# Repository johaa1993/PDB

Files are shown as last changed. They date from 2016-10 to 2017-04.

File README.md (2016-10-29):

# PDB

# Kill switch
The goal is to switch high power with low power (TTL logic level).
If somethings goes wrong then the user might want to kill the system until further damages happens.

Mechanical relay or MOSFET can be used for such application.

## MOSFET driver
The MOSFET can be damaged if driven incorectly.

### Drain-source resistance `R_ds`
Applying gate-source voltage will decrease drain-source resistance over time. If the drain-source resistance decreases too slow while drain-source current is conducted then the MOSFET will heat up and possably get damaged. The time it takes to reach fully turned on MOSFET depends on gate capacitance, gate resistance and the MOSFET gate driver ability to deliver current.

### Gate-source voltage `V_GS`
Applying too high gate-source voltage will damage the MOSFET.

### Parasitic oscillation
The MOSFET internal capacitance and the wires inductance combined will inevitably create a RLC curcuit.
A step response on the `V_GS` will have a oscilation. Higher gate resistance => higher damping, higher switch time. Lower gate resistance => lower damping, lower switch time.
It's up to the user to find a fine balance between the switch time and parasitic oscillation.

### [LM5050](http://www.ti.com/lit/ds/symlink/lm5050-1-q1.pdf)
MOSFET gate driver. 

http://toshiba.semicon-storage.com/us/design-support/document/application-note.html
Application Precautions: Power MOSFET Application Notes

### More
Taking all these into consideration when designing a MOSFET driver is a hard task.

# Current sensor
The goal is to measure the both high current, low current.

# Fuse
The goal is too protect from short curcuit.

# Power status
The goal is to check if there power on the line.

# Battery cell monitor
The goal is to check if the battery cell is to low.

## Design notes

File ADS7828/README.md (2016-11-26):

# ADC to I2C test circuit for PDB

This circuit is to test the [ADS7828](http://www.ti.com/lit/ds/symlink/ads7828.pdf)

## ADS7828

>The [ADS7828](http://www.ti.com/lit/ds/symlink/ads7828.pdf) is a single-supply, low-power, 12-bit data
>acquisition device that features a serial I2C interface and an
>8-channel multiplexer. The Analog-to-Digital (A/D) converter
>features a sample-and-hold amplifier and internal,
>asynchronous clock. The combination of an I2C serial,
>2-wire interface and micropower consumption makes the
>ADS7828 ideal for applications requiring the A/D converter to
>be close to the input source in remote locations and for
>applications requiring isolation. The ADS7828 is available in
>a TSSOP-16 package.

## Test circuit

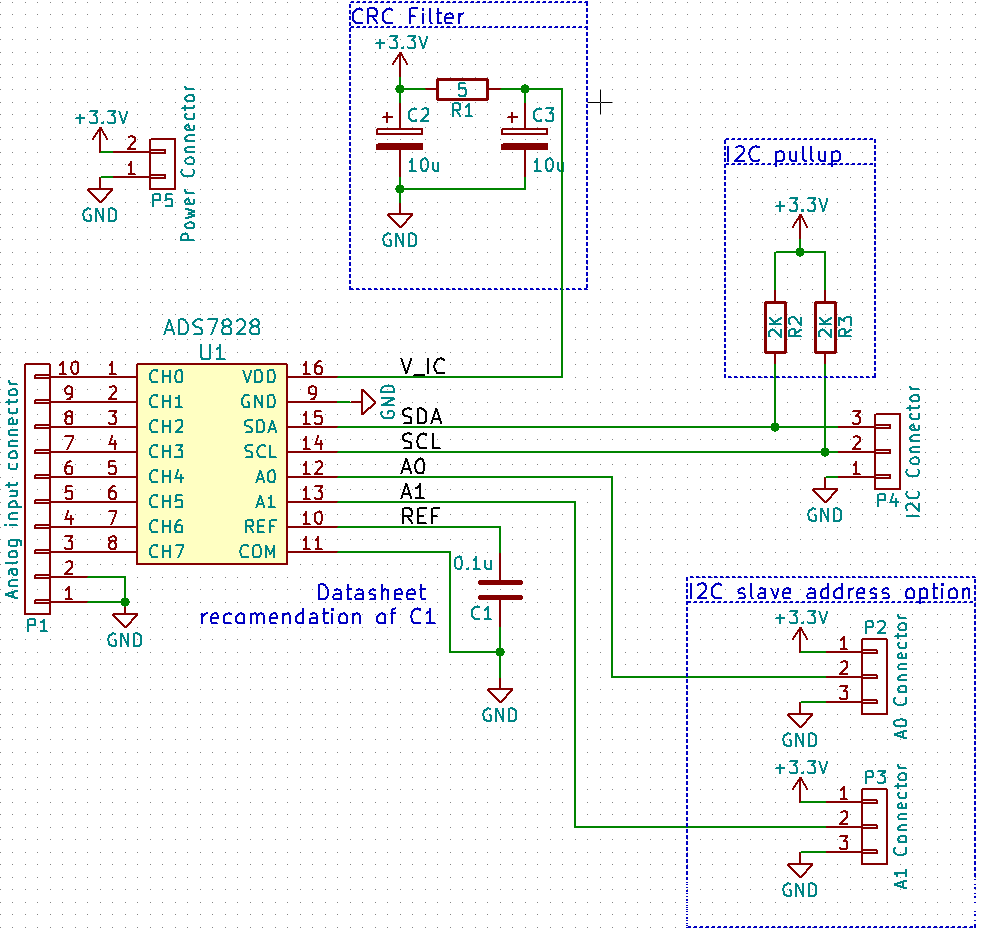
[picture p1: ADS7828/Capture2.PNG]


### CRC Filter
The CRC filter reduces noise for the `V_IC`.

### I2C pull-up
> I2C are open drain, which means that they can pull a signal line low, but they are unable to drive it high.

The I2C pull-up is there in case of microcontroller is not having a internal pull-up.

### I2C slave address option
`3.3V` or `GND` connected to `A0` and `A1` is required in order to provide a slave address. The 7 bit slave address is `(1, 0, 0, 1, 0, A1, A0)` where `GND` is logic a `0` and `3.3V` is a logic `1`.

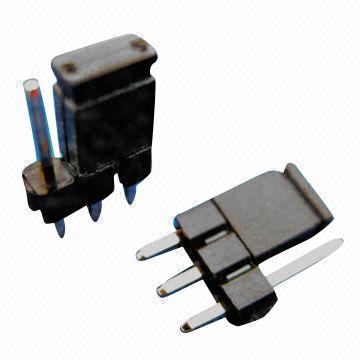
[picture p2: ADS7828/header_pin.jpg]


If header pin for `P2` and `P3` is used, an header pin jumper can be used to select slave address.

### Internal reference voltage
If 3.3V is used then `REF` does not need external voltage.

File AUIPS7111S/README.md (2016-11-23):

# AUIPS7111S

> The [AUIPS7111S](http://www.farnell.com/datasheets/1441780.pdf) is a fully protected four terminal high
> side switch. It features current sensing, over-current, over-
> temperature, ESD protection and drain to source active
> clamp. When the input voltage Vcc - Vin is higher than the
> specified threshold, the output power Mosfet is turned on.
> When the Vcc - Vin is lower than the specified Vil
> threshold, the output Mosfet
> is turned off. The Ifb pin is
> used for current sensing.

## AUIPS7111S Test curcuit

This is a prototype sub part of PDB.

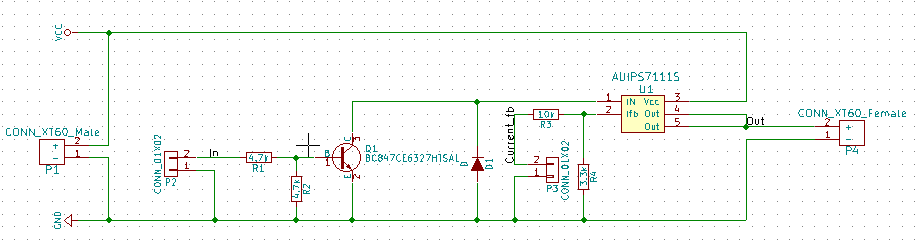
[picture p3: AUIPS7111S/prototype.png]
Image of prototype


The voltage across R4 is `V_R4 = R_4 * I_fb`. So we can configurate the R4 to set the current sense voltage propotional constant to current draw.

`V_R4 = R_4 * I_VCC_Out / Ratio`

### Parts

| Part  | Function  |
|-----|---|
| P1  | Power input |
| P4  | Power output  |
| R1  | Current limiter for BJT. Prevent destroying the BJT or waste power.  |
| R2  | Passive pull down for BJT. We want to make sure the U1 is passively off in case of signal `In` is high impedance.  |
| D1  | Protection for BJT in case of reverse current.  |
| U1  | Switch, current sensing.  |
| R4  | Voltage gain for current sensing. Resistance from `I_fb` to `GND` is max 1.5k [datasheet](http://www.farnell.com/datasheets/1441780.pdf)  |
| R3  | Protection for U1. Resistance from `I_fb` to `GND` is max 1.5k [datasheet](http://www.farnell.com/datasheets/1441780.pdf)  |
| P2  | Input. Connector to control the U1. |
| P3  | Output. Current feedback. |

### Truth table
| `P2_In`  | `U1`  |
|---|---|
| High | On |
| Low | Off |
| High impedance | Off |

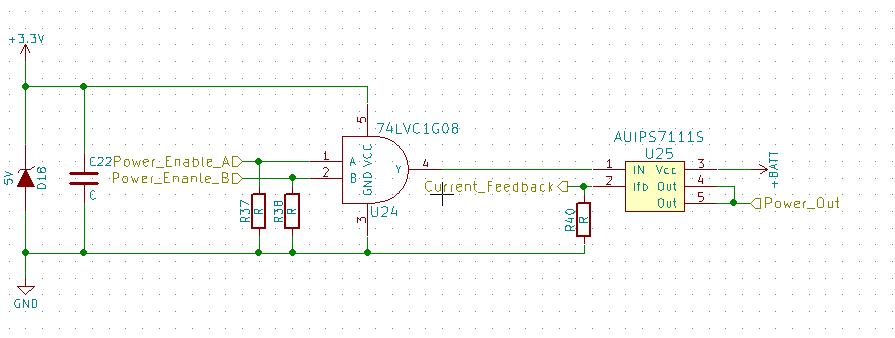
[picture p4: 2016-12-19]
PDB5/concept_pwr_logic.PNG

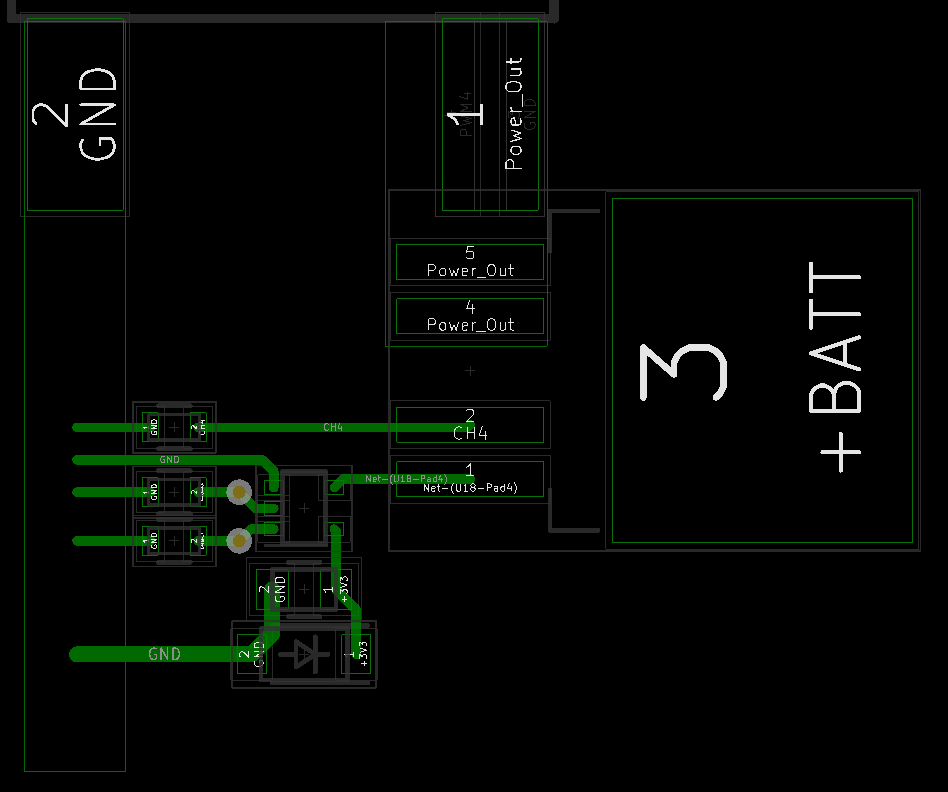
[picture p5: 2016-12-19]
PDB5/concept_pwr_switch_2.PNG

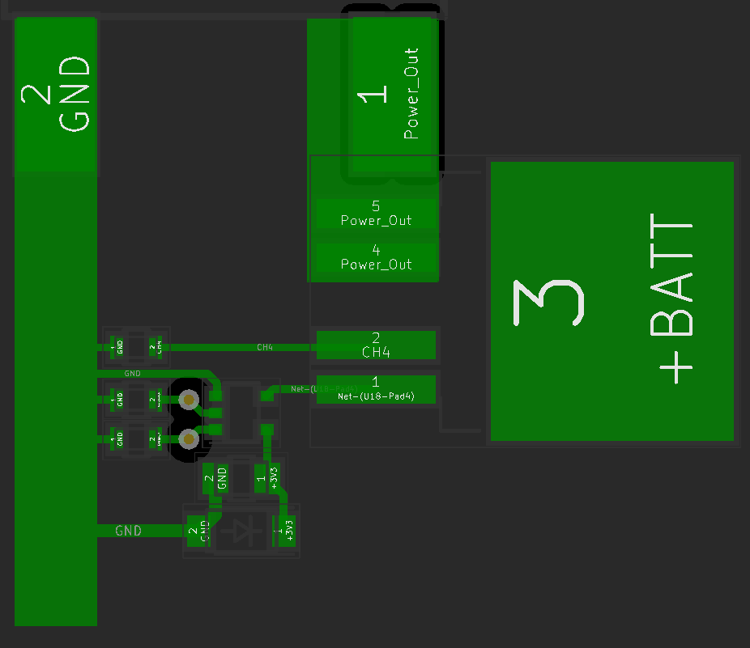
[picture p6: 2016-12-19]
PDB5/concept_pwr_switch.PNG

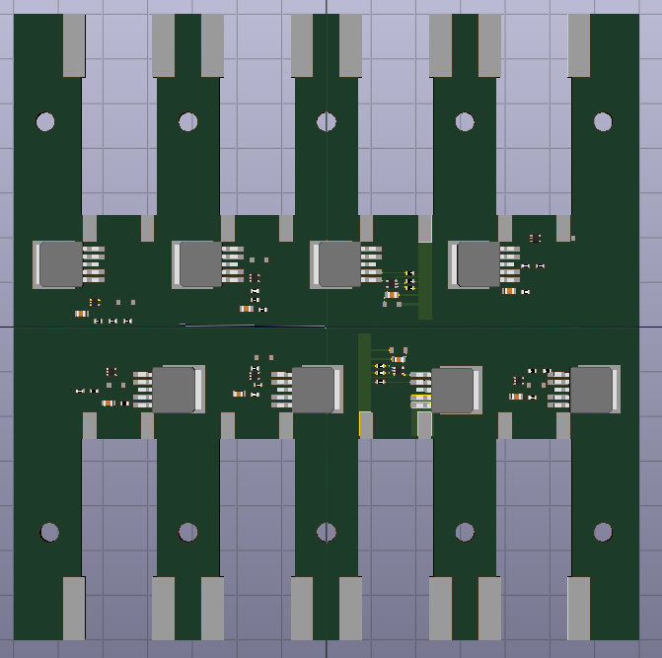
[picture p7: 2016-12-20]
PDB5/concept_1.PNG

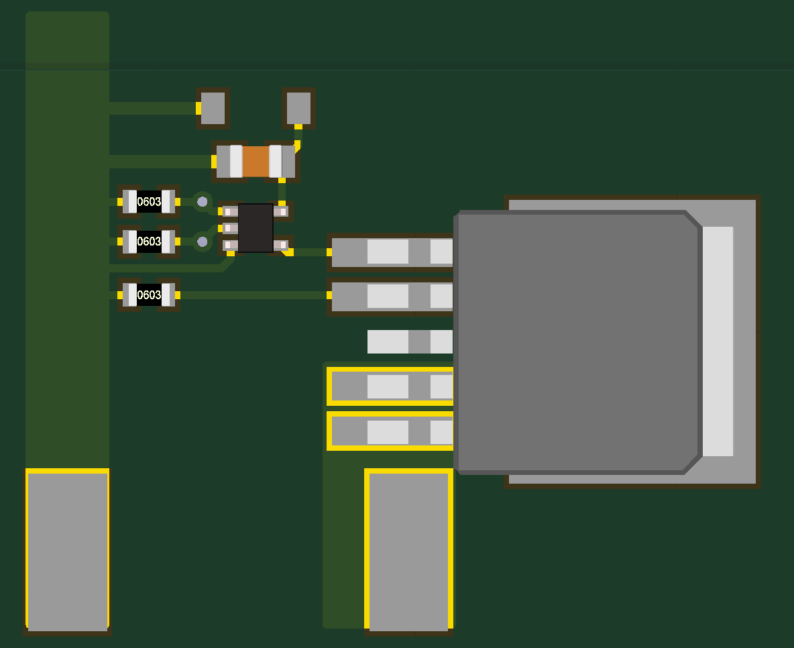
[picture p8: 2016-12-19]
PDB5/concept_pwr_switch_3.PNG

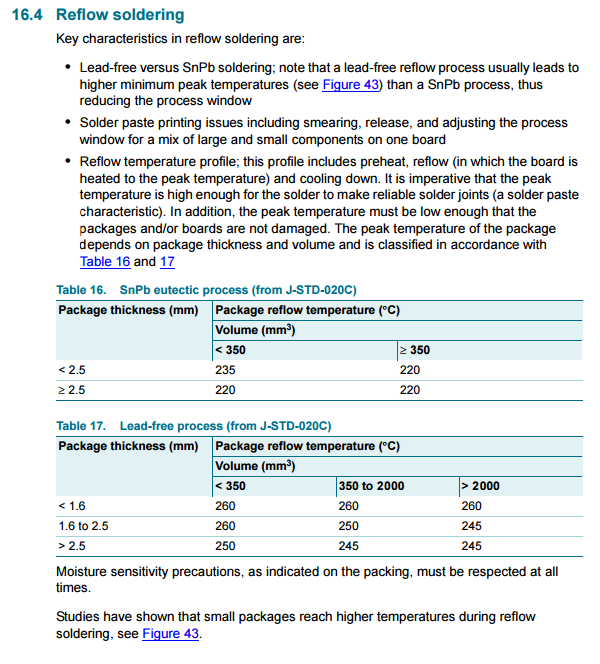
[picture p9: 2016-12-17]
PDB5/Reflow.PNG

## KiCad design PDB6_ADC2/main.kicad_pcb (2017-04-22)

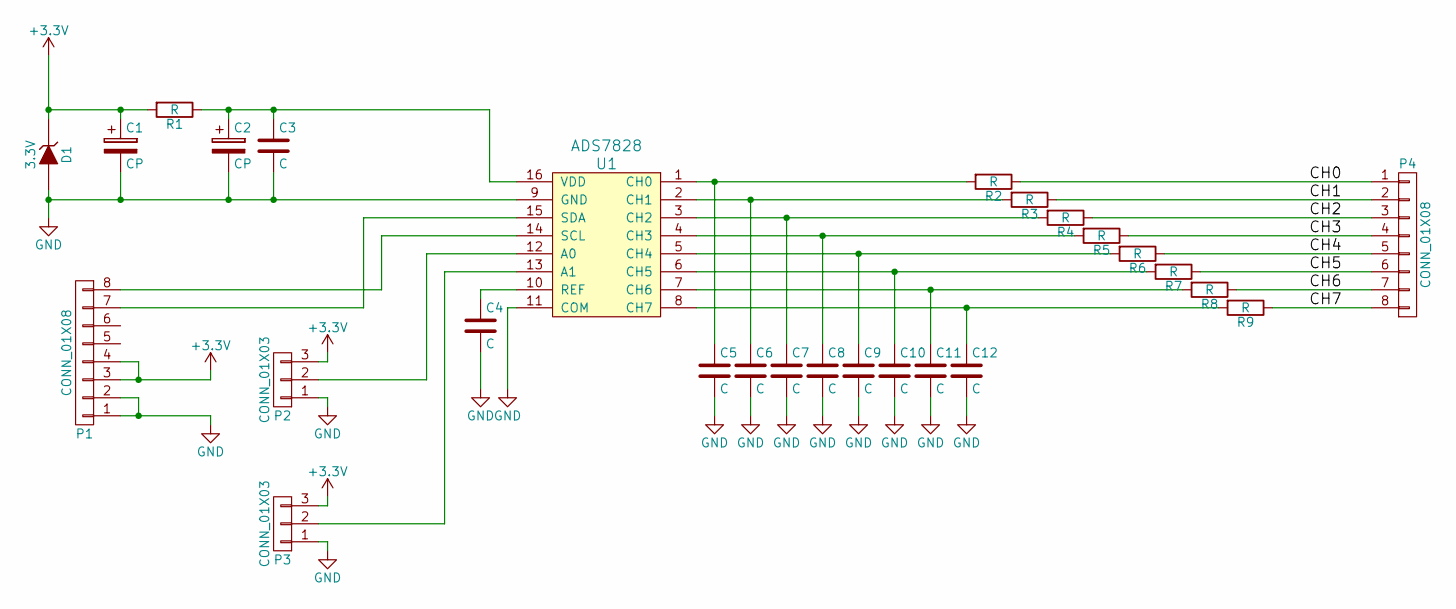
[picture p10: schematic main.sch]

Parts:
C1, C2: CP; SMD-1206_Pol
C3, C4, C5, C6, C7, C8, C9, C10, C11, C12: C; C_0805
D1: 3.3V; SOD-123
P1, P4: CONN_01X08; Pin_Header_Straight_1x08_Pitch2.00mm
P2, P3: CONN_01X03; Pad_3
R1, R2, R3, R4, R5, R6, R7, R8, R9: R; R_0805
U1: ADS7828; TSSOP-16_4.4x5mm_Pitch0.65mm

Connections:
+3V3: C1.1, D1.1 (K), P1.3, P1.4, P2.3, P3.3, R1.2
/CH0: P4.1, R2.1
/CH1: P4.2, R3.1
/CH2: P4.3, R4.1
/CH3: P4.4, R5.1
/CH4: P4.5, R6.1
/CH5: P4.6, R7.1
/CH6: P4.7, R8.1
/CH7: P4.8, R9.1
GND: C1.2, C2.2, C3.2, C4.2, C5.2, C6.2, C7.2, C8.2, C9.2, C10.2, C11.2, C12.2, D1.2 (A), P1.1, P1.2, P2.1, P3.1, U1.9 (GND), U1.11 (COM)
unnamed: C2.1, C3.1, R1.1, U1.16 (VDD)
unnamed: C4.1, U1.10 (REF)
unnamed: C5.1, R2.2, U1.1 (CH0)
unnamed: C6.1, R3.2, U1.2 (CH1)
unnamed: C7.1, R4.2, U1.3 (CH2)
unnamed: C8.1, R5.2, U1.4 (CH3)
unnamed: C9.1, R6.2, U1.5 (CH4)
unnamed: C10.1, R7.2, U1.6 (CH5)
unnamed: C11.1, R8.2, U1.7 (CH6)
unnamed: C12.1, R9.2, U1.8 (CH7)
unnamed: P1.7, U1.15 (SDA)
unnamed: P1.8, U1.14 (SCL)
unnamed: P2.2, U1.12 (A0)
unnamed: P3.2, U1.13 (A1)

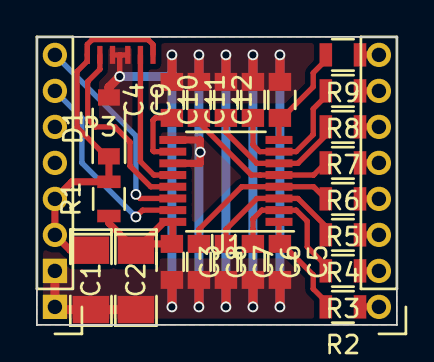
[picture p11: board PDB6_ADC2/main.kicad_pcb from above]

Board: 2 copper layers, 20.0 x 16.0 mm, 27 parts (0 on the bottom side), 24 nets.

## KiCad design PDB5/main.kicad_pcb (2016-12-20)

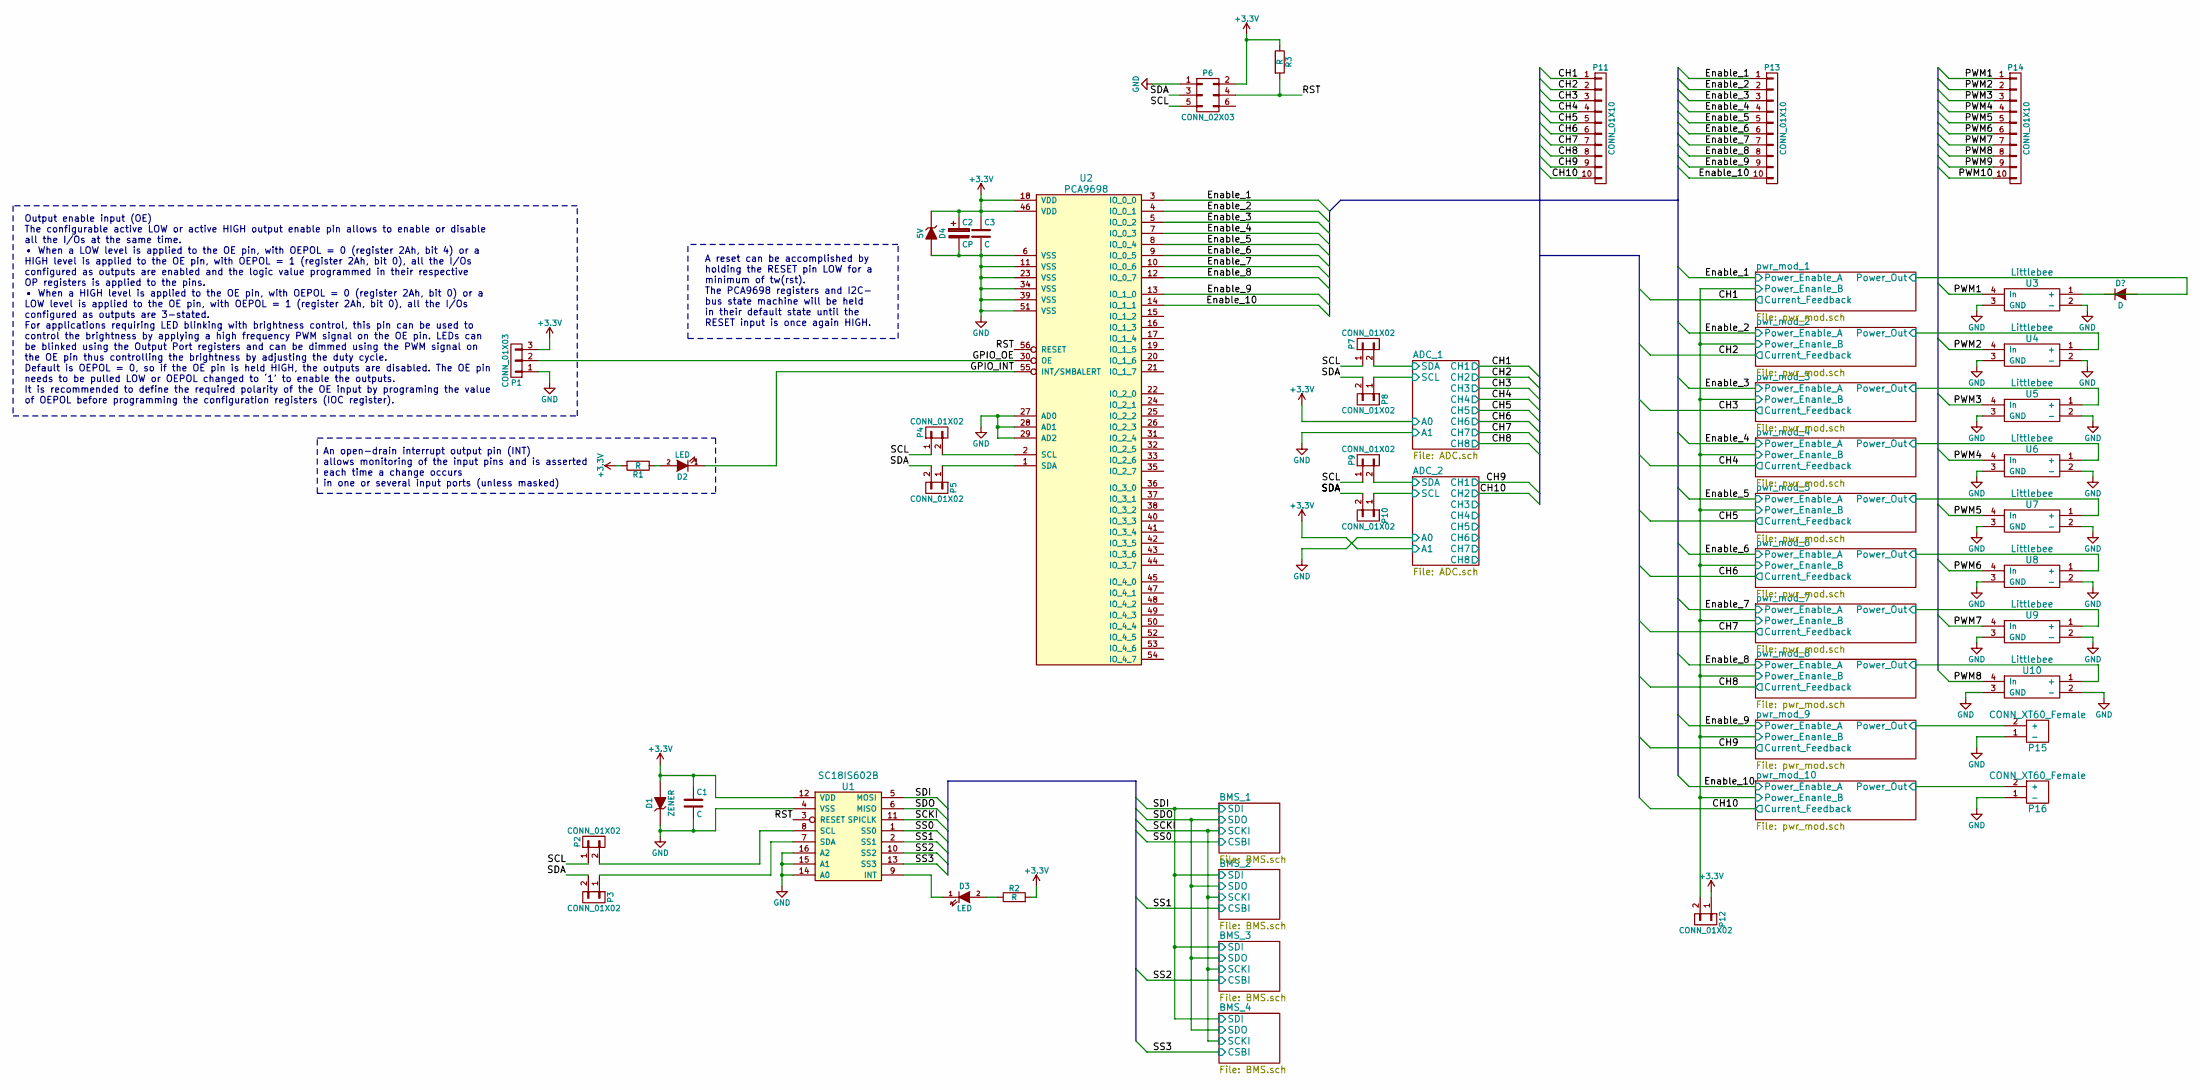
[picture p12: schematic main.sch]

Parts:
C1, C3: C; C_0805
C2: CP; SMD-2010_Pol
D1: ZENER; SOD-123
D2, D3: LED; LED_0603
D4: 5V; SOD-123
P1: CONN_01X03; Pin_Header_Straight_1x03
P2, P3, P4, P5, P7, P8, P9, P10, P12: CONN_01X02; Pin_Header_Straight_1x02
P6: CONN_02X03; Pin_Header_Straight_2x03
P11, P13, P14: CONN_01X10; Pin_Header_Straight_1x10
P15, P16: CONN_XT60_Female; XT60
R1, R2: R; R_0603
R3: R
U1: SC18IS602B; TSSOP-16_4.4x5mm_Pitch0.65mm
U2: PCA9698; TSSOP-56_6.1x14mm_Pitch0.5mm
U3, U4, U5, U6, U7, U8, U9, U10: Littlebee

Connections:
+3V3: C1.1, C2.1, C3.1, D1.2 (A), D4.1 (K), P1.3, P6.2, P12.1, R1.2, R2.2, R3.1, U1.12 (VDD), U2.18 (VDD), U2.46 (VDD); also elsewhere on the board
/ADC_1/SCL: P8.1; also elsewhere on the board
/ADC_1/SDA: P7.2; also elsewhere on the board
/ADC_2/SCL: P10.1; also elsewhere on the board
/ADC_2/SDA: P9.2; also elsewhere on the board
/CH1: P11.1; also elsewhere on the board
/CH2: P11.2; also elsewhere on the board
/CH3: P11.3; also elsewhere on the board
/CH4: P11.4; also elsewhere on the board
/CH5: P11.5; also elsewhere on the board
/CH6: P11.6; also elsewhere on the board
/CH7: P11.7; also elsewhere on the board
/CH8: P11.8; also elsewhere on the board
/CH9: P11.9; also elsewhere on the board
/CH10: P11.10; also elsewhere on the board
/Enable_1: P13.1, U2.3 (IO_0_0); also elsewhere on the board
/Enable_2: P13.2, U2.4 (IO_0_1); also elsewhere on the board
/Enable_3: P13.3, U2.5 (IO_0_2); also elsewhere on the board
/Enable_4: P13.4, U2.7 (IO_0_3); also elsewhere on the board
/Enable_5: P13.5, U2.8 (IO_0_4); also elsewhere on the board
/Enable_6: P13.6, U2.9 (IO_0_5); also elsewhere on the board
/Enable_7: P13.7, U2.10 (IO_0_6); also elsewhere on the board
/Enable_8: P13.8, U2.12 (IO_0_7); also elsewhere on the board
/Enable_9: P13.9, U2.13 (IO_1_0); also elsewhere on the board
/Enable_10: P13.10, U2.14 (IO_1_1); also elsewhere on the board
/GPIO_INT: D2.1 (K), U2.55 (INT/SMBALERT)
/GPIO_OE: P1.2, U2.30 (OE)
/PWM1: P14.1, U3.4 (In)
/PWM2: P14.2, U4.4 (In)
/PWM3: P14.3, U5.4 (In)
/PWM4: P14.4, U6.4 (In)
/PWM5: P14.5, U7.4 (In)
/PWM6: P14.6, U8.4 (In)
/PWM7: P14.7, U9.4 (In)
/PWM8: P14.8, U10.4 (In)
/RST: P6.4, R3.2, U1.3 (RESET), U2.56 (RESET)
/SCKI: U1.11 (SPICLK); also elsewhere on the board
/SCL: P2.1, P4.1, P6.5, P7.1, P9.1
/SDA: P3.2, P5.2, P6.3, P8.2, P10.2
/SDI: U1.5 (MOSI); also elsewhere on the board
/SDO: U1.6 (MISO); also elsewhere on the board
/SS0: U1.1 (SS0); also elsewhere on the board
/SS1: U1.2 (SS1); also elsewhere on the board
/SS2: U1.10 (SS2); also elsewhere on the board
/SS3: U1.13 (SS3); also elsewhere on the board
/pwr_mod_1/Power_Enanle_B: P12.2; also elsewhere on the board
/pwr_mod_1/Power_Out: U3.1 (+); also elsewhere on the board
/pwr_mod_2/Power_Out: U4.1 (+); also elsewhere on the board
/pwr_mod_3/Power_Out: U5.1 (+); also elsewhere on the board
/pwr_mod_4/Power_Out: U6.1 (+); also elsewhere on the board
/pwr_mod_5/Power_Out: U7.1 (+); also elsewhere on the board
/pwr_mod_6/Power_Out: U8.1 (+); also elsewhere on the board
/pwr_mod_7/Power_Out: U9.1 (+); also elsewhere on the board
/pwr_mod_8/Power_Out: U10.1 (+); also elsewhere on the board
/pwr_mod_9/Power_Out: P15.2 (+); also elsewhere on the board
/pwr_mod_10/Power_Out: P16.2 (+); also elsewhere on the board
GND: C1.2, C2.2, C3.2, D1.1 (K), D4.2 (A), P1.1, P6.1, P15.1 (-), P16.1 (-), U1.4 (VSS), U1.14 (A0), U1.15 (A1), U1.16 (A2), U2.6 (VSS), U2.11 (VSS), U2.23 (VSS), U2.27 (AD0), U2.28 (AD1), U2.29 (AD2), U2.34 (VSS), U2.39 (VSS), U2.51 (VSS), U3.2 (-), U3.3 (GND), U4.2 (-), U4.3 (GND), U5.2 (-), U5.3 (GND), U6.2 (-), U6.3 (GND), U7.2 (-), U7.3 (GND), U8.2 (-), U8.3 (GND), U9.2 (-), U9.3 (GND), U10.2 (-), U10.3 (GND); also elsewhere on the board
unnamed: D2.2 (A), R1.1
unnamed: D3.1 (K), U1.9 (INT)
unnamed: D3.2 (A), R2.1
unnamed: P2.2, U1.8 (SCL)
unnamed: P3.1, U1.7 (SDA)
unnamed: P4.2, U2.2 (SCL)
unnamed: P5.1, U2.1 (SDA)

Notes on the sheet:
An open-drain interrupt output pin (INT) allows monitoring of the input pins and is asserted each time a change occurs in one or several input ports (unless masked)
Output enable input (OE) The configurable active LOW or active HIGH output enable pin allows to enable or disable all the I/Os at the same time. • When a LOW level is applied to the OE pin, with OEPOL = 0 (register 2Ah, bit 4) or a HIGH level is applied to the OE pin, with OEPOL = 1 (register 2Ah, 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
A reset can be accomplished by holding the RESET pin LOW for a minimum of tw(rst). The PCA9698 registers and I2C- bus state machine will be held in their default state until the RESET input is once again HIGH.

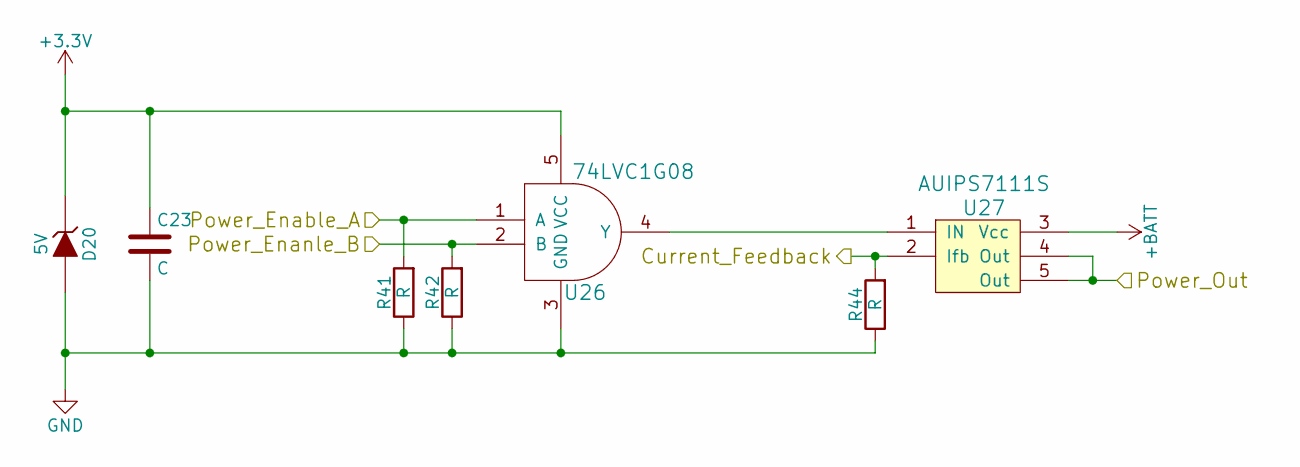
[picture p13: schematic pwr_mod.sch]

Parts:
C4: C; C_0805
D5: 5V; SOD-123
R4, R7, R26: R; R_0603
U11: 74LVC1G08; SOT-353
U12: AUIPS7111S; TO-263-!3

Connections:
+3V3: C4.1, D5.1 (K), U11.5 (VCC); also elsewhere on the board
+BATT: U12.3 (Vcc); also elsewhere on the board
/CH1: R7.2, U12.2 (Ifb); also elsewhere on the board
/Enable_1: R4.2, U11.1 (A); also elsewhere on the board
/pwr_mod_1/Power_Enanle_B: R26.2, U11.2 (B); also elsewhere on the board
/pwr_mod_1/Power_Out: U12.4 (Out), U12.5 (Out); also elsewhere on the board
GND: C4.2, D5.2 (A), R4.1, R7.1, R26.1, U11.3 (GND); also elsewhere on the board
unnamed: U11.4 (Y), U12.1 (IN)

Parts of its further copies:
C5, C18, C19, C20, C21, C22, C23, C24, C25: C; C_0805
D7, D10, D12, D14, D16, D18, D20, D22, D24: 5V; SOD-123
R5, R8, R9, R11, R21, R22, R24, R25, R28, R29, R30, R32, R33, R34, R36, R37, R38, R40, R41, R42, R44, R45, R46, R48, R49, R50, R52: R; R_0603
U13, U16, U18, U20, U22, U24, U26, U28, U30: 74LVC1G08; SOT-353
U14, U17, U19, U21, U23, U25, U27, U29, U31: AUIPS7111S; TO-263-!3

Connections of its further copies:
+3V3: C5.1, C18.1, C19.1, C20.1, C21.1, C22.1, C23.1, C24.1, C25.1, D7.1 (K), D10.1 (K), D12.1 (K), D14.1 (K), D16.1 (K), D18.1 (K), D20.1 (K), D22.1 (K), D24.1 (K), U13.5 (VCC), U16.5 (VCC), U18.5 (VCC), U20.5 (VCC), U22.5 (VCC), U24.5 (VCC), U26.5 (VCC), U28.5 (VCC), U30.5 (VCC); also elsewhere on the board
+BATT: U14.3 (Vcc), U17.3 (Vcc), U19.3 (Vcc), U21.3 (Vcc), U23.3 (Vcc), U25.3 (Vcc), U27.3 (Vcc), U29.3 (Vcc), U31.3 (Vcc); also elsewhere on the board
/CH2: R11.2, U14.2 (Ifb); also elsewhere on the board
/CH3: R24.2, U17.2 (Ifb); also elsewhere on the board
/CH4: R28.2, U19.2 (Ifb); also elsewhere on the board
/CH5: R32.2, U21.2 (Ifb); also elsewhere on the board
/CH6: R36.2, U23.2 (Ifb); also elsewhere on the board
/CH7: R40.2, U25.2 (Ifb); also elsewhere on the board
/CH8: R44.2, U27.2 (Ifb); also elsewhere on the board
/CH9: R48.2, U29.2 (Ifb); also elsewhere on the board
/CH10: R52.2, U31.2 (Ifb); also elsewhere on the board
/Enable_2: R8.2, U13.1 (A); also elsewhere on the board
/Enable_3: R21.2, U16.1 (A); also elsewhere on the board
/Enable_4: R25.2, U18.1 (A); also elsewhere on the board
/Enable_5: R29.2, U20.1 (A); also elsewhere on the board
/Enable_6: R33.2, U22.1 (A); also elsewhere on the board
/Enable_7: R37.2, U24.1 (A); also elsewhere on the board
/Enable_8: R41.2, U26.1 (A); also elsewhere on the board
/Enable_9: R45.2, U28.1 (A); also elsewhere on the board
/Enable_10: R49.2, U30.1 (A); also elsewhere on the board
/pwr_mod_1/Power_Enanle_B: R5.2, R9.2, R22.2, R30.2, R34.2, R38.2, R42.2, R46.2, R50.2, U13.2 (B), U16.2 (B), U18.2 (B), U20.2 (B), U22.2 (B), U24.2 (B), U26.2 (B), U28.2 (B), U30.2 (B); also elsewhere on the board
/pwr_mod_2/Power_Out: U14.4 (Out), U14.5 (Out); also elsewhere on the board
/pwr_mod_3/Power_Out: U17.4 (Out), U17.5 (Out); also elsewhere on the board
/pwr_mod_4/Power_Out: U19.4 (Out), U19.5 (Out); also elsewhere on the board
/pwr_mod_5/Power_Out: U21.4 (Out), U21.5 (Out); also elsewhere on the board
/pwr_mod_6/Power_Out: U23.4 (Out), U23.5 (Out); also elsewhere on the board
/pwr_mod_7/Power_Out: U25.4 (Out), U25.5 (Out); also elsewhere on the board
/pwr_mod_8/Power_Out: U27.4 (Out), U27.5 (Out); also elsewhere on the board
/pwr_mod_9/Power_Out: U29.4 (Out), U29.5 (Out); also elsewhere on the board
/pwr_mod_10/Power_Out: U31.4 (Out), U31.5 (Out); also elsewhere on the board
GND: C5.2, C18.2, C19.2, C20.2, C21.2, C22.2, C23.2, C24.2, C25.2, D7.2 (A), D10.2 (A), D12.2 (A), D14.2 (A), D16.2 (A), D18.2 (A), D20.2 (A), D22.2 (A), D24.2 (A), R5.1, R8.1, R9.1, R11.1, R21.1, R22.1, R24.1, R25.1, R28.1, R29.1, R30.1, R32.1, R33.1, R34.1, R36.1, R37.1, R38.1, R40.1, R41.1, R42.1, R44.1, R45.1, R46.1, R48.1, R49.1, R50.1, R52.1, U13.3 (GND), U16.3 (GND), U18.3 (GND), U20.3 (GND), U22.3 (GND), U24.3 (GND), U26.3 (GND), U28.3 (GND), U30.3 (GND); also elsewhere on the board
unnamed: U13.4 (Y), U14.1 (IN)
unnamed: U16.4 (Y), U17.1 (IN)
unnamed: U18.4 (Y), U19.1 (IN)
unnamed: U20.4 (Y), U21.1 (IN)
unnamed: U22.4 (Y), U23.1 (IN)
unnamed: U24.4 (Y), U25.1 (IN)
unnamed: U26.4 (Y), U27.1 (IN)
unnamed: U28.4 (Y), U29.1 (IN)
unnamed: U30.4 (Y), U31.1 (IN)

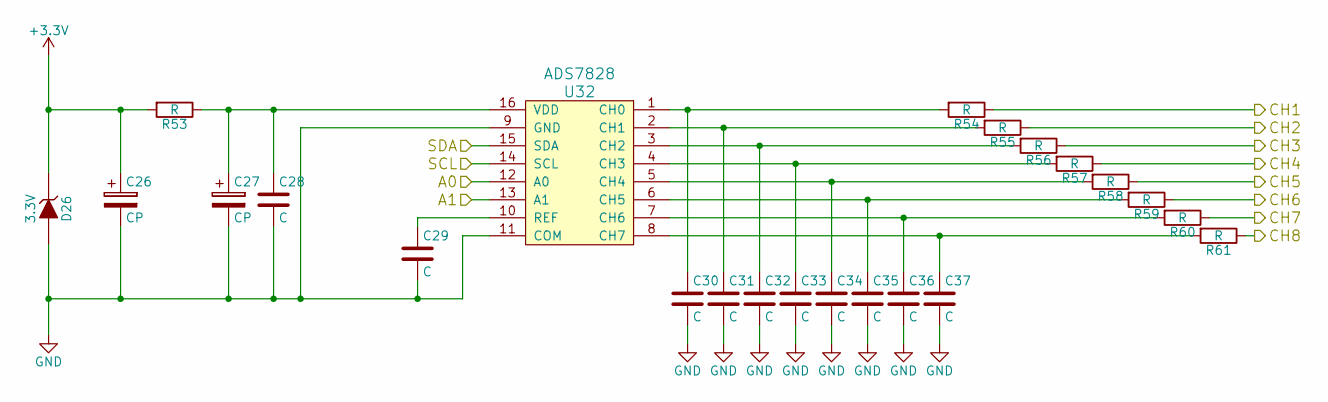
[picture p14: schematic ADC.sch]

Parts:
C6, C7: CP; SMD-2010_Pol
C8, C9, C10, C11, C12, C13, C14, C15, C16, C17: C; C_0805
D9: 3.3V; SOD-123
R12, R13, R14, R15, R16, R17, R18, R19, R20: R; R_0603
U15: ADS7828; TSSOP-16_4.4x5mm_Pitch0.65mm

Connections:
+3V3: C6.1, D9.1 (K), R12.2, U15.12 (A0); also elsewhere on the board
/ADC_1/SCL: U15.14 (SCL); also elsewhere on the board
/ADC_1/SDA: U15.15 (SDA); also elsewhere on the board
/CH1: R13.1; also elsewhere on the board
/CH2: R14.1; also elsewhere on the board
/CH3: R15.1; also elsewhere on the board
/CH4: R16.1; also elsewhere on the board
/CH5: R17.1; also elsewhere on the board
/CH6: R18.1; also elsewhere on the board
/CH7: R19.1; also elsewhere on the board
/CH8: R20.1; also elsewhere on the board
GND: C6.2, C7.2, C8.2, C9.2, C10.2, C11.2, C12.2, C13.2, C14.2, C15.2, C16.2, C17.2, D9.2 (A), U15.9 (GND), U15.11 (COM), U15.13 (A1); also elsewhere on the board
unnamed: C7.1, C8.1, R12.1, U15.16 (VDD)
unnamed: C9.1, U15.10 (REF)
unnamed: C10.1, R13.2, U15.1 (CH0)
unnamed: C11.1, R14.2, U15.2 (CH1)
unnamed: C12.1, R15.2, U15.3 (CH2)
unnamed: C13.1, R16.2, U15.4 (CH3)
unnamed: C14.1, R17.2, U15.5 (CH4)
unnamed: C15.1, R18.2, U15.6 (CH5)
unnamed: C16.1, R19.2, U15.7 (CH6)
unnamed: C17.1, R20.2, U15.8 (CH7)

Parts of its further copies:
C26, C27: CP; SMD-2010_Pol
C28, C29, C30, C31, C32, C33, C34, C35, C36, C37: C; C_0805
D26: 3.3V; SOD-123
R53, R54, R55, R56, R57, R58, R59, R60, R61: R; R_0603
U32: ADS7828; TSSOP-16_4.4x5mm_Pitch0.65mm

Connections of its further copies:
+3V3: C26.1, D26.1 (K), R53.2, U32.13 (A1); also elsewhere on the board
/ADC_2/SCL: U32.14 (SCL); also elsewhere on the board
/ADC_2/SDA: U32.15 (SDA); also elsewhere on the board
/CH9: R54.1; also elsewhere on the board
/CH10: R55.1; also elsewhere on the board
GND: C26.2, C27.2, C28.2, C29.2, C30.2, C31.2, C32.2, C33.2, C34.2, C35.2, C36.2, C37.2, D26.2 (A), U32.9 (GND), U32.11 (COM), U32.12 (A0); also elsewhere on the board
unnamed: C27.1, C28.1, R53.1, U32.16 (VDD)
unnamed: C29.1, U32.10 (REF)
unnamed: C30.1, R54.2, U32.1 (CH0)
unnamed: C31.1, R55.2, U32.2 (CH1)
unnamed: C32.1, R56.2, U32.3 (CH2)
unnamed: C33.1, R57.2, U32.4 (CH3)
unnamed: C34.1, R58.2, U32.5 (CH4)
unnamed: C35.1, R59.2, U32.6 (CH5)
unnamed: C36.1, R60.2, U32.7 (CH6)
unnamed: C37.1, R61.2, U32.8 (CH7)

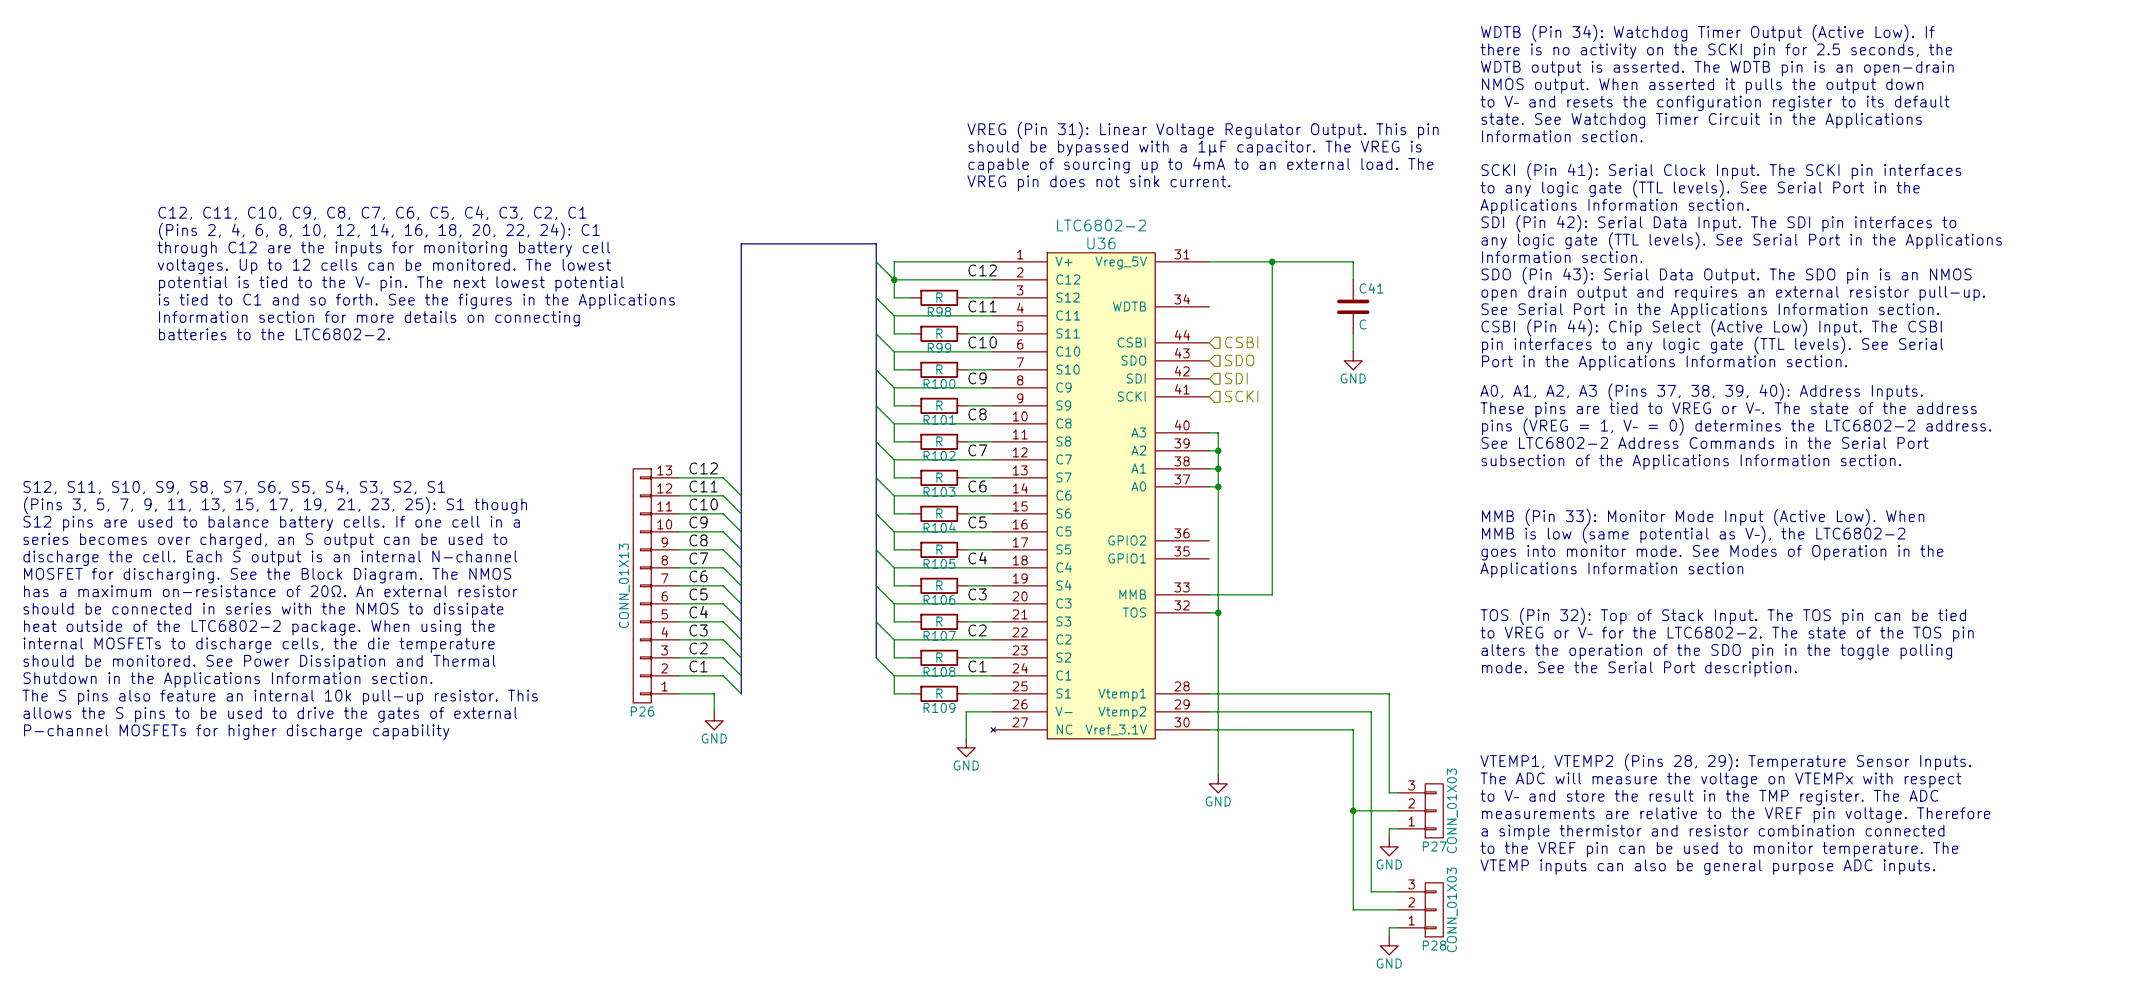
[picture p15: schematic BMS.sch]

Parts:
C38: C; C_0805
P17: CONN_01X13; Pin_Header_Straight_1x13
P18, P19: CONN_01X03; Pin_Header_Straight_1x03
R62, R63, R64, R65, R66, R67, R68, R69, R70, R71, R72, R73: R; R_0805
U33: LTC6802-2; SSOP-44

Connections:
/BMS_1/C1: P17.2, R73.2, U33.24 (C1)
/BMS_1/C2: P17.3, R72.2, U33.22 (C2)
/BMS_1/C3: P17.4, R71.2, U33.20 (C3)
/BMS_1/C4: P17.5, R70.2, U33.18 (C4)
/BMS_1/C5: P17.6, R69.2, U33.16 (C5)
/BMS_1/C6: P17.7, R68.2, U33.14 (C6)
/BMS_1/C7: P17.8, R67.2, U33.12 (C7)
/BMS_1/C8: P17.9, R66.2, U33.10 (C8)
/BMS_1/C9: P17.10, R65.2, U33.8 (C9)
/BMS_1/C10: P17.11, R64.2, U33.6 (C10)
/BMS_1/C11: P17.12, R63.2, U33.4 (C11)
/BMS_1/C12: P17.13, R62.2, U33.1 (V+), U33.2 (C12)
/SCKI: U33.41 (SCKI); also elsewhere on the board
/SDI: U33.42 (SDI); also elsewhere on the board
/SDO: U33.43 (SDO); also elsewhere on the board
/SS0: U33.44 (CSBI); also elsewhere on the board
GND: C38.2, P17.1, P18.1, P19.1, U33.26 (V-), U33.32 (TOS), U33.37 (A0), U33.38 (A1), U33.39 (A2), U33.40 (A3); also elsewhere on the board
unnamed: C38.1, U33.31 (Vreg_5V), U33.33 (MMB)
unnamed: P18.2, P19.2, U33.30 (Vref_3.1V)
unnamed: P18.3, U33.28 (Vtemp1)
unnamed: P19.3, U33.29 (Vtemp2)
unnamed: R62.1, U33.3 (S12)
unnamed: R63.1, U33.5 (S11)
unnamed: R64.1, U33.7 (S10)
unnamed: R65.1, U33.9 (S9)
unnamed: R66.1, U33.11 (S8)
unnamed: R67.1, U33.13 (S7)
unnamed: R68.1, U33.15 (S6)
unnamed: R69.1, U33.17 (S5)
unnamed: R70.1, U33.19 (S4)
unnamed: R71.1, U33.21 (S3)
unnamed: R72.1, U33.23 (S2)
unnamed: R73.1, U33.25 (S1)

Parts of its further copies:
C39, C40, C41: C; C_0805
P20, P23, P26: CONN_01X13; Pin_Header_Straight_1x13
P21, P22, P24, P25, P27, P28: CONN_01X03; Pin_Header_Straight_1x03
R74, R75, R76, R77, R78, R79, R80, R81, R82, R83, R84, R85, R86, R87, R88, R89, R90, R91, R92, R93, R94, R95, R96, R97, R98, R99, R100, R101, R102, R103, R104, R105, R106, R107, R108, R109: R; R_0805
U34, U35, U36: LTC6802-2; SSOP-44

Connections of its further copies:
/BMS_2/C1: P20.2, R85.2, U34.24 (C1)
/BMS_2/C2: P20.3, R84.2, U34.22 (C2)
/BMS_2/C3: P20.4, R83.2, U34.20 (C3)
/BMS_2/C4: P20.5, R82.2, U34.18 (C4)
/BMS_2/C5: P20.6, R81.2, U34.16 (C5)
/BMS_2/C6: P20.7, R80.2, U34.14 (C6)
/BMS_2/C7: P20.8, R79.2, U34.12 (C7)
/BMS_2/C8: P20.9, R78.2, U34.10 (C8)
/BMS_2/C9: P20.10, R77.2, U34.8 (C9)
/BMS_2/C10: P20.11, R76.2, U34.6 (C10)
/BMS_2/C11: P20.12, R75.2, U34.4 (C11)
/BMS_2/C12: P20.13, R74.2, U34.1 (V+), U34.2 (C12)
/BMS_3/C1: P23.2, R97.2, U35.24 (C1)
/BMS_3/C2: P23.3, R96.2, U35.22 (C2)
/BMS_3/C3: P23.4, R95.2, U35.20 (C3)
/BMS_3/C4: P23.5, R94.2, U35.18 (C4)
/BMS_3/C5: P23.6, R93.2, U35.16 (C5)
/BMS_3/C6: P23.7, R92.2, U35.14 (C6)
/BMS_3/C7: P23.8, R91.2, U35.12 (C7)
/BMS_3/C8: P23.9, R90.2, U35.10 (C8)
/BMS_3/C9: P23.10, R89.2, U35.8 (C9)
/BMS_3/C10: P23.11, R88.2, U35.6 (C10)
/BMS_3/C11: P23.12, R87.2, U35.4 (C11)
/BMS_3/C12: P23.13, R86.2, U35.1 (V+), U35.2 (C12)
/BMS_4/C1: P26.2, R109.2, U36.24 (C1)
/BMS_4/C2: P26.3, R108.2, U36.22 (C2)
/BMS_4/C3: P26.4, R107.2, U36.20 (C3)
/BMS_4/C4: P26.5, R106.2, U36.18 (C4)
/BMS_4/C5: P26.6, R105.2, U36.16 (C5)
/BMS_4/C6: P26.7, R104.2, U36.14 (C6)
/BMS_4/C7: P26.8, R103.2, U36.12 (C7)
/BMS_4/C8: P26.9, R102.2, U36.10 (C8)
/BMS_4/C9: P26.10, R101.2, U36.8 (C9)
/BMS_4/C10: P26.11, R100.2, U36.6 (C10)
/BMS_4/C11: P26.12, R99.2, U36.4 (C11)
/BMS_4/C12: P26.13, R98.2, U36.1 (V+), U36.2 (C12)
/SCKI: U34.41 (SCKI), U35.41 (SCKI), U36.41 (SCKI); also elsewhere on the board
/SDI: U34.42 (SDI), U35.42 (SDI), U36.42 (SDI); also elsewhere on the board
/SDO: U34.43 (SDO), U35.43 (SDO), U36.43 (SDO); also elsewhere on the board
/SS1: U34.44 (CSBI); also elsewhere on the board
/SS2: U35.44 (CSBI); also elsewhere on the board
/SS3: U36.44 (CSBI); also elsewhere on the board
GND: C39.2, C40.2, C41.2, P20.1, P21.1, P22.1, P23.1, P24.1, P25.1, P26.1, P27.1, P28.1, U34.26 (V-), U34.32 (TOS), U34.37 (A0), U34.38 (A1), U34.39 (A2), U34.40 (A3), U35.26 (V-), U35.32 (TOS), U35.37 (A0), U35.38 (A1), U35.39 (A2), U35.40 (A3), U36.26 (V-), U36.32 (TOS), U36.37 (A0), U36.38 (A1), U36.39 (A2), U36.40 (A3); also elsewhere on the board
unnamed: C39.1, U34.31 (Vreg_5V), U34.33 (MMB)
unnamed: C40.1, U35.31 (Vreg_5V), U35.33 (MMB)
unnamed: C41.1, U36.31 (Vreg_5V), U36.33 (MMB)
unnamed: P21.2, P22.2, U34.30 (Vref_3.1V)
unnamed: P21.3, U34.28 (Vtemp1)
unnamed: P22.3, U34.29 (Vtemp2)
unnamed: P24.2, P25.2, U35.30 (Vref_3.1V)
unnamed: P24.3, U35.28 (Vtemp1)
unnamed: P25.3, U35.29 (Vtemp2)
unnamed: P27.2, P28.2, U36.30 (Vref_3.1V)
unnamed: P27.3, U36.28 (Vtemp1)
unnamed: P28.3, U36.29 (Vtemp2)
unnamed: R74.1, U34.3 (S12)
unnamed: R75.1, U34.5 (S11)
unnamed: R76.1, U34.7 (S10)
unnamed: R77.1, U34.9 (S9)
unnamed: R78.1, U34.11 (S8)
unnamed: R79.1, U34.13 (S7)
unnamed: R80.1, U34.15 (S6)
unnamed: R81.1, U34.17 (S5)
unnamed: R82.1, U34.19 (S4)
unnamed: R83.1, U34.21 (S3)
unnamed: R84.1, U34.23 (S2)
unnamed: R85.1, U34.25 (S1)
unnamed: R86.1, U35.3 (S12)
unnamed: R87.1, U35.5 (S11)
unnamed: R88.1, U35.7 (S10)
unnamed: R89.1, U35.9 (S9)
unnamed: R90.1, U35.11 (S8)
unnamed: R91.1, U35.13 (S7)
unnamed: R92.1, U35.15 (S6)
unnamed: R93.1, U35.17 (S5)
unnamed: R94.1, U35.19 (S4)
unnamed: R95.1, U35.21 (S3)
unnamed: R96.1, U35.23 (S2)
unnamed: R97.1, U35.25 (S1)
unnamed: R98.1, U36.3 (S12)
unnamed: R99.1, U36.5 (S11)
unnamed: R100.1, U36.7 (S10)
unnamed: R101.1, U36.9 (S9)
unnamed: R102.1, U36.11 (S8)
unnamed: R103.1, U36.13 (S7)
unnamed: R104.1, U36.15 (S6)
unnamed: R105.1, U36.17 (S5)
unnamed: R106.1, U36.19 (S4)
unnamed: R107.1, U36.21 (S3)
unnamed: R108.1, U36.23 (S2)
unnamed: R109.1, U36.25 (S1)

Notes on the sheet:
WDTB (Pin 34): Watchdog Timer Output (Active Low). If there is no activity on the SCKI pin for 2.5 seconds, the WDTB output is asserted. The WDTB pin is an open-drain NMOS output. When asserted it pulls the output down to V– and resets the configuration register to its default state. See Watchdog T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
VTEMP1, VTEMP2 (Pins 28, 29): Temperature Sensor Inputs. The ADC will measure the voltage on VTEMPx with respect to V– and store the result in the TMP register. The ADC measurements are relative to the VREF pin voltage. Therefore a simple thermistor and resistor combination connected to the VREF pi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
SCKI (Pin 41): Serial Clock Input. The SCKI pin interfaces to any logic gate (TTL levels). See Serial Port in the Applications Information section. SDI (Pin 42): Serial Data Input. The SDI pin interfaces to any logic gate (TTL levels). See Serial Port in the Applications Information section. SDO (P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
C12, C11, C10, C9, C8, C7, C6, C5, C4, C3, C2, C1 (Pins 2, 4, 6, 8, 10, 12, 14, 16, 18, 20, 22, 24): C1 through C12 are the inputs for monitoring battery cell voltages. Up to 12 cells can be monitored. The lowest potential is tied to the V– pin. The next lowest potential is tied to C1 and so forth.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
S12, S11, S10, S9, S8, S7, S6, S5, S4, S3, S2, S1 (Pins 3, 5, 7, 9, 11, 13, 15, 17, 19, 21, 23, 25): S1 though S12 pins are used to balance battery cells. If one cell in a series becomes over charged, an S output can be used to discharge the cell. Each S output is an internal N-channel MOSFET for d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
MMB (Pin 33): Monitor Mode Input (Active Low). When MMB is low (same potential as V–), the LTC6802-2 goes into monitor mode. See Modes of Operation in the Applications Information section
TOS (Pin 32): Top of Stack Input. The TOS pin can be tied to VREG or V– for the LTC6802-2. The state of the TOS pin alters the operation of the SDO pin in the toggle polling mode. See the Serial Port description.
A0, A1, A2, A3 (Pins 37, 38, 39, 40): Address Inputs. These pins are tied to VREG or V–. The state of the address pins (VREG = 1, V– = 0) determines the LTC6802-2 address. See LTC6802-2 Address Commands in the Serial Port subsection of the Applications Information section.
VREG (Pin 31): Linear Voltage Regulator Output. This pin should be bypassed with a 1µF capacitor. The VREG is capable of sourcing up to 4mA to an external load. The VREG pin does not sink current.

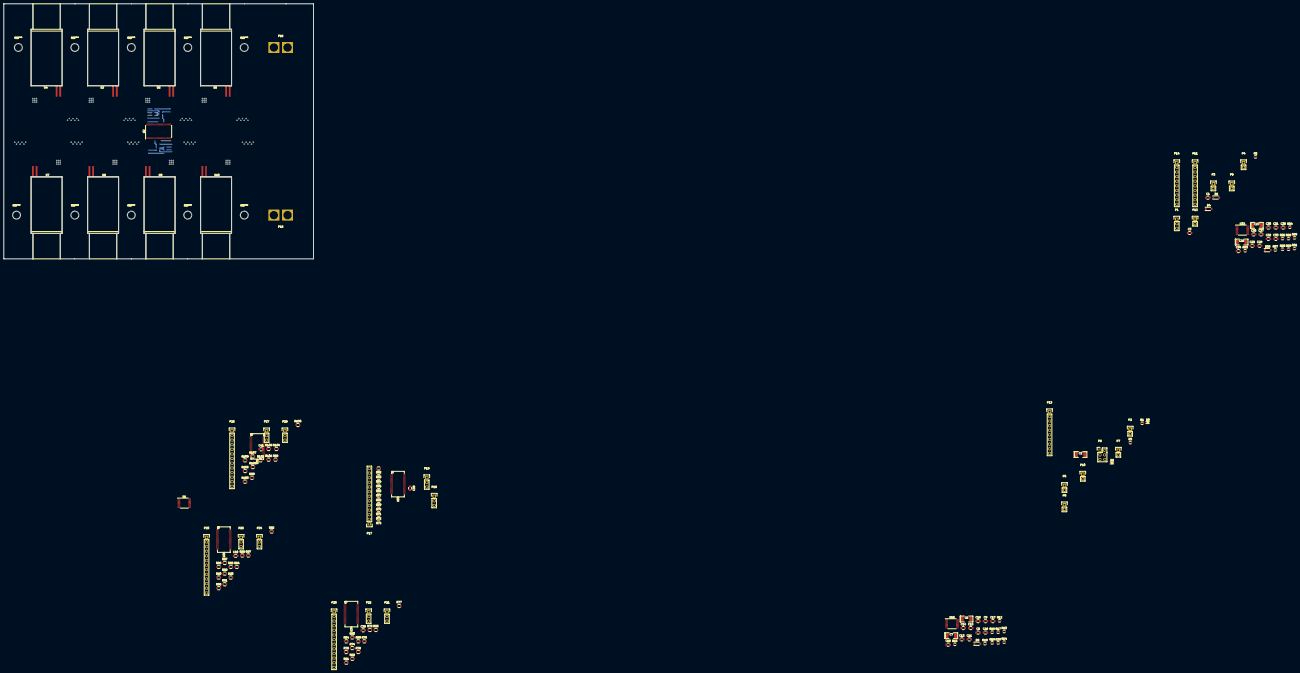
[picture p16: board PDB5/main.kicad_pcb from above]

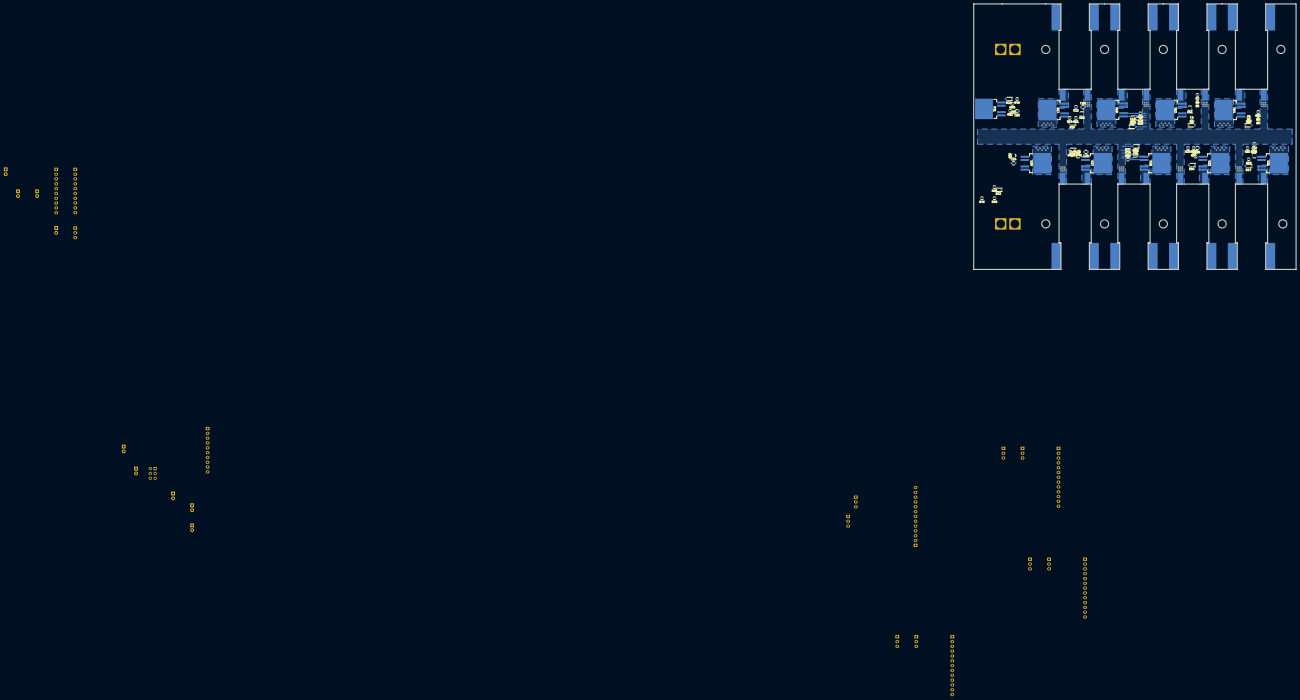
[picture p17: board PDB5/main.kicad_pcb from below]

Board: 4 copper layers, 170.0 x 140.0 mm, 220 parts (70 on the bottom side), 207 nets.

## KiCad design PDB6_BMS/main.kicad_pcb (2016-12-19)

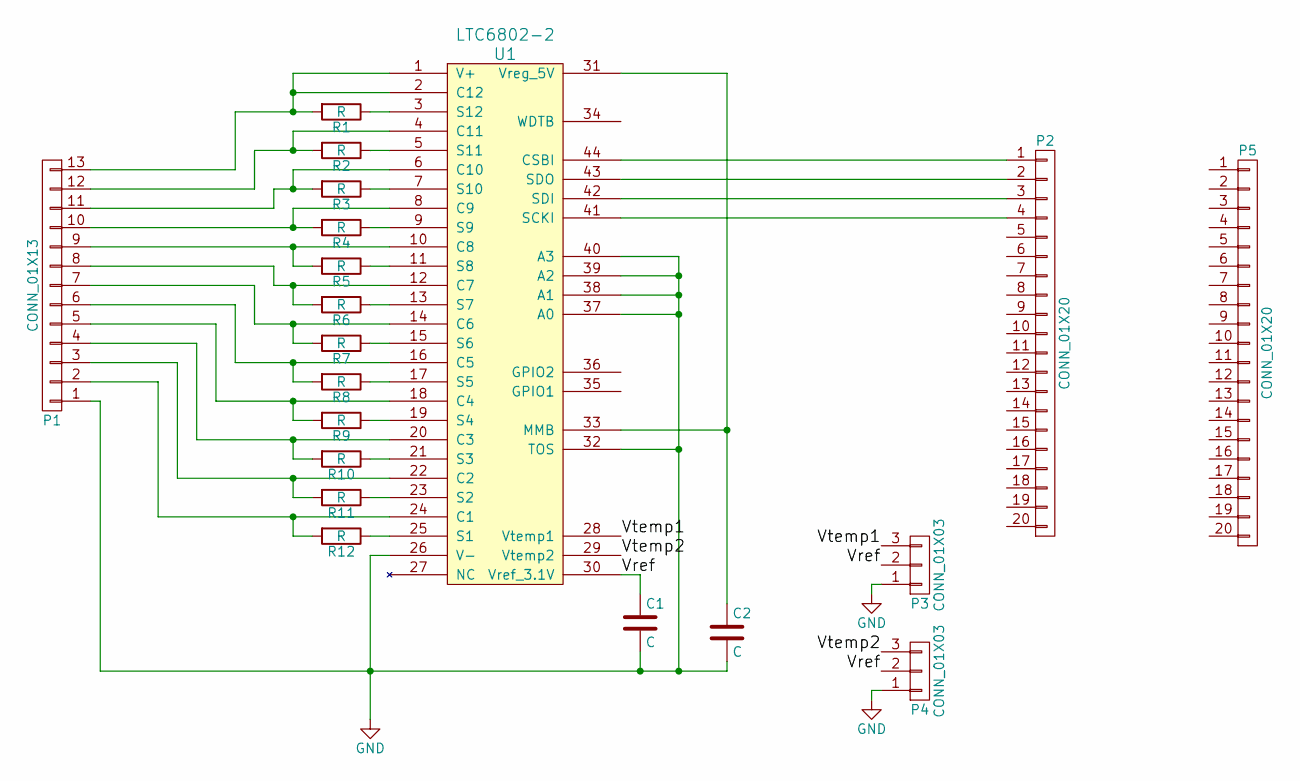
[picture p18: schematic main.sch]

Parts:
C1, C2: C; C_0805
P1: CONN_01X13; Pin_Header_Straight_1x13
P2, P5: CONN_01X20; Pin_Header_Straight_1x20_Pitch2.00mm
P3, P4: CONN_01X03; Pin_Header_Straight_1x03
R1, R2, R3, R4, R5, R6, R7, R8, R9, R10, R11, R12: R; R_0805
U1: LTC6802-2; SSOP-44

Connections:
/Vref: C1.1, P3.2, P4.2, U1.30 (Vref_3.1V)
/Vtemp1: P3.3, U1.28 (Vtemp1)
/Vtemp2: P4.3, U1.29 (Vtemp2)
GND: C1.2, C2.2, P1.1, P3.1, P4.1, U1.26 (V-), U1.32 (TOS), U1.37 (A0), U1.38 (A1), U1.39 (A2), U1.40 (A3)
unnamed: C2.1, U1.31 (Vreg_5V), U1.33 (MMB)
unnamed: P1.2, R12.2, U1.24 (C1)
unnamed: P1.3, R11.2, U1.22 (C2)
unnamed: P1.4, R10.2, U1.20 (C3)
unnamed: P1.5, R9.2, U1.18 (C4)
unnamed: P1.6, R8.2, U1.16 (C5)
unnamed: P1.7, R7.2, U1.14 (C6)
unnamed: P1.8, R6.2, U1.12 (C7)
unnamed: P1.9, R5.2, U1.10 (C8)
unnamed: P1.10, R4.2, U1.8 (C9)
unnamed: P1.11, R3.2, U1.6 (C10)
unnamed: P1.12, R2.2, U1.4 (C11)
unnamed: P1.13, R1.2, U1.1 (V+), U1.2 (C12)
unnamed: P2.1, U1.44 (CSBI)
unnamed: P2.2, U1.43 (SDO)
unnamed: P2.3, U1.42 (SDI)
unnamed: P2.4, U1.41 (SCKI)
unnamed: R1.1, U1.3 (S12)
unnamed: R2.1, U1.5 (S11)
unnamed: R3.1, U1.7 (S10)
unnamed: R4.1, U1.9 (S9)
unnamed: R5.1, U1.11 (S8)
unnamed: R6.1, U1.13 (S7)
unnamed: R7.1, U1.15 (S6)
unnamed: R8.1, U1.17 (S5)
unnamed: R9.1, U1.19 (S4)
unnamed: R10.1, U1.21 (S3)
unnamed: R11.1, U1.23 (S2)
unnamed: R12.1, U1.25 (S1)

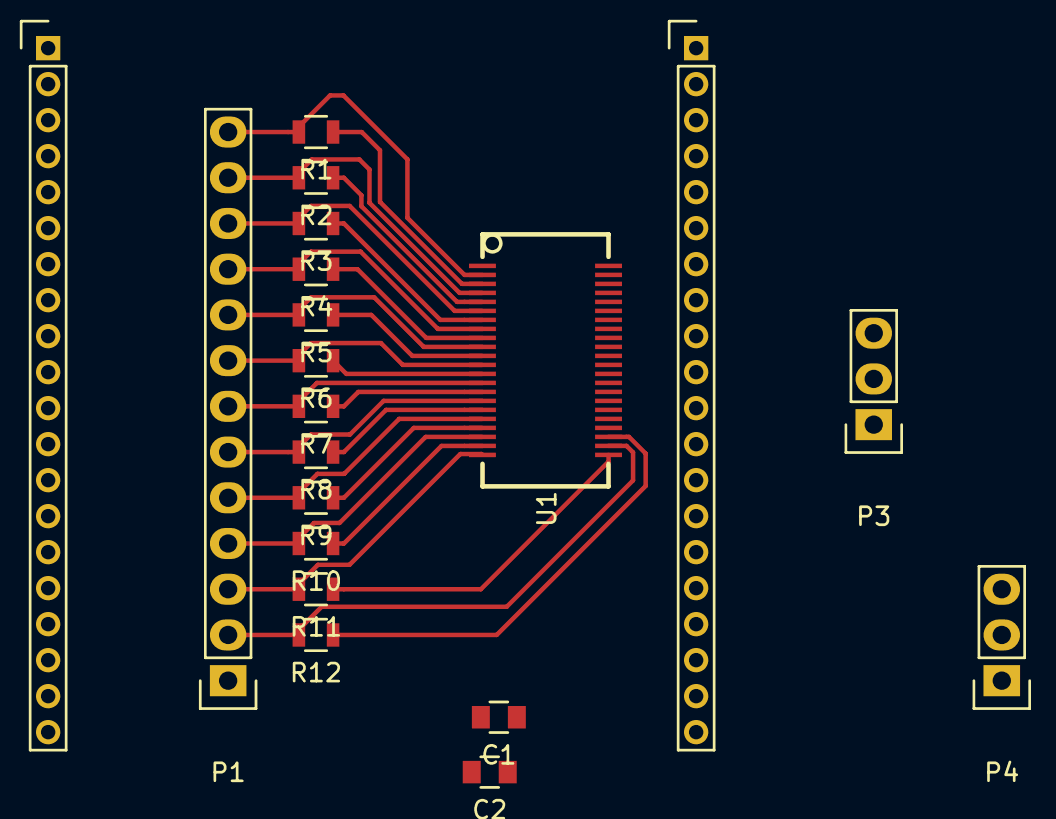
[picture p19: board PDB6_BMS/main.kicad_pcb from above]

Board: 2 copper layers, 20 parts (0 on the bottom side), 33 nets.

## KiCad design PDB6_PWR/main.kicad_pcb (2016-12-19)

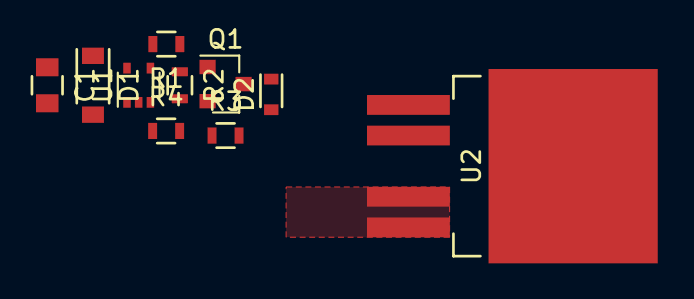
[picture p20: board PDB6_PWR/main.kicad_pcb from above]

Board: 2 copper layers, 10 parts (0 on the bottom side), 7 nets, no tracks yet.

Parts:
C1: C; C_0805
D1: 5V; SOD-123
D2: D; D_0603
Q1: BC847CE6327HTSA1; SOT-23
R1, R2, R3, R4: R; R_0603
U1: 74LVC1G08; SOT-353
U2: AUIPS7111S; TO-263-5Lead

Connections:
+3V3: C1.1, D1.1, U1.5
/Power_Out: U2.4, U2.5
GND: C1.2, D1.2, D2.2, Q1.2, R2.2, R4.1, U1.3
unnamed: D2.1, Q1.3, U2.1
unnamed: Q1.1, R1.1, R2.1
unnamed: R1.2, U1.4
unnamed: R3.1, R4.2, U2.2

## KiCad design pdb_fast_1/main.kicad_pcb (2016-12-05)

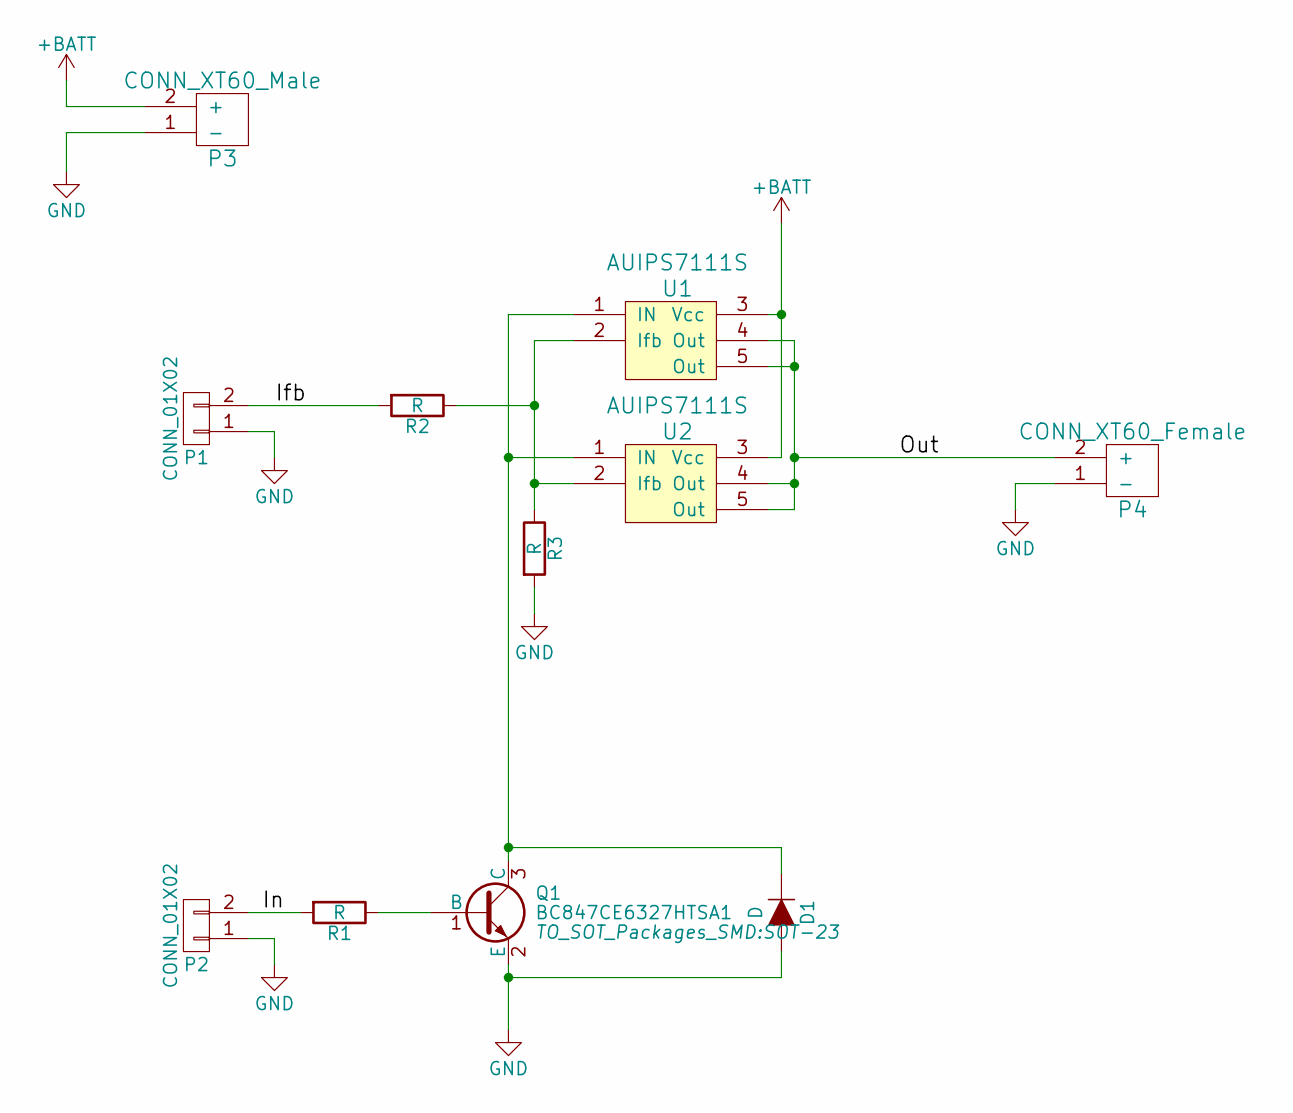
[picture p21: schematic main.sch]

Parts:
D1: D; SOD-123
P1, P2: CONN_01X02; Pin_Header_Straight_1x02
P3: CONN_XT60_Male; CONN_XT60_Male1_Horizontal
P4: CONN_XT60_Female; CONN_XT60_Male2_Horizontal
Q1: BC847CE6327HTSA1; SOT-23
R1, R2, R3: R; R_0603
U1, U2: AUIPS7111S; TO-263-!3

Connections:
+BATT: P3.2 (+), U1.3 (Vcc), U2.3 (Vcc)
/Ifb: P1.2, R2.2
/In: P2.2, R1.2
/Out: P4.2 (+), U1.4 (Out), U1.5 (Out), U2.4 (Out), U2.5 (Out)
GND: D1.2 (A), P1.1, P2.1, P3.1 (-), P4.1 (-), Q1.2 (E), R3.2
unnamed: D1.1 (K), Q1.3 (C), U1.1 (IN), U2.1 (IN)
unnamed: Q1.1 (B), R1.1
unnamed: R2.1, R3.1, U1.2 (Ifb), U2.2 (Ifb)

Board: 2 copper layers, 11 parts (0 on the bottom side), 8 nets, no tracks yet.

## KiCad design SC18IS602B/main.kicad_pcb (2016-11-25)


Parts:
D1: LED; LED_0805
P1: CONN_01X02; Pin_Header_Straight_1x02
P2, P3, P4, P5, P6: CONN_01X03; Pin_Header_Straight_1x03
P7, P8: CONN_01X04; Pin_Header_Straight_1x04
R1: R; Resistor_Horizontal_RM7mm
U1: SC18IS602B; TSSOP-16_4.4x5mm_Pitch0.65mm

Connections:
+3V3: P1.2, P2.3, P4.3, P5.3, P6.3, R1.1, U1.12 (VDD)
/A0: P6.2, U1.14 (A0)
/A1: P5.2, U1.15 (A1)
/A2: P4.2, U1.16 (A2)
/INT: D1.1 (K), U1.9 (INT)
/MISO: P8.4, U1.6 (MISO)
/MOSI: P8.3, U1.5 (MOSI)
/Reset: P2.2, U1.3 (RESET)
/SCL: P3.3, U1.8 (SCL)
/SDA: P3.2, U1.7 (SDA)
/SPICLK: P8.2, U1.11 (SPICLK)
/SS0: P7.2, U1.1 (SS0)
/SS1: P7.1, U1.2 (SS1)
/SS2: P7.3, U1.10 (SS2)
/SS3: P7.4, U1.13 (SS3)
GND: P1.1, P2.1, P3.1, P4.1, P5.1, P6.1, P8.1, U1.4 (VSS)
unnamed: D1.2 (A), R1.2



Board: 2 copper layers, 53.3 x 55.9 mm, 11 parts (9 on the bottom side), 17 nets.

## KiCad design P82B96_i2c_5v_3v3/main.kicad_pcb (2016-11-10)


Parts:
P1, P2: CONN_01X04; Pin_Header_Angled_1x04
R1, R2, R3, R4: 1k; R_0805
U1: P82B96; SOIC-8_3.9x4.9mm_Pitch1.27mm

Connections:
+3V3: P2.1, R3.1, R4.1
+5V: P1.4, R1.1, R2.1, U1.8 (VCC)
/SCL0: P1.2, R1.2, U1.7 (SCL)
/SCL1: P2.3, R4.2, U1.5 (TXD-SCL), U1.6 (RXD-SCL)
/SDA0: P1.3, R2.2, U1.1 (SDA)
/SDA1: P2.2, R3.2, U1.2 (RXD-SDA), U1.3 (TXD-SDA)
GND: P1.1, P2.4, U1.4 (GND)



Board: 2 copper layers, 27.9 x 12.7 mm, 7 parts (2 on the bottom side), 7 nets.

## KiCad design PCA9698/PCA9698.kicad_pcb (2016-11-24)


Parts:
D1: LED; LED_0805
P1: Power connector; Pin_Header_Straight_1x10
P2, P4, P10: CONN_01X03; Pin_Header_Straight_1x03
P3: I2C connector; Pin_Header_Straight_1x05
P5: GPIO 0; Pin_Header_Straight_1x08
P6: GPIO 1; Pin_Header_Straight_1x08
P7: GPIO 2; Pin_Header_Straight_1x08
P8: GPIO 3; Pin_Header_Straight_1x08
P9: GPIO 4; Pin_Header_Straight_1x08
R1: R; R_0805
U2: PCA9698; TSSOP-56_6.1x14mm_Pitch0.5mm

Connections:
+3V3: P1.6, P1.7, P1.8, P1.9, P1.10, P2.3, P10.3, R1.2, U2.18 (VDD), U2.46 (VDD)
/INT: D1.1 (K), U2.55 (INT/SMBALERT)
/OE: P2.2, U2.30 (OE)
/Reset: P10.2, U2.56 (RESET)
/SCL: P3.4, P3.5, U2.2 (SCL)
/SDA: P3.2, P3.3, U2.1 (SDA)
GND: P1.1, P1.2, P1.3, P1.4, P1.5, P2.1, P3.1, P10.1, U2.6 (VSS), U2.11 (VSS), U2.23 (VSS), U2.34 (VSS), U2.39 (VSS), U2.51 (VSS)
unnamed: D1.2 (A), R1.1
unnamed: P4.1, U2.29 (AD2)
unnamed: P4.2, U2.28 (AD1)
unnamed: P4.3, U2.27 (AD0)
unnamed: P5.1, U2.3 (IO_0_0)
unnamed: P5.2, U2.4 (IO_0_1)
unnamed: P5.3, U2.5 (IO_0_2)
unnamed: P5.4, U2.7 (IO_0_3)
unnamed: P5.5, U2.8 (IO_0_4)
unnamed: P5.6, U2.9 (IO_0_5)
unnamed: P5.7, U2.10 (IO_0_6)
unnamed: P5.8, U2.12 (IO_0_7)
unnamed: P6.1, U2.13 (IO_1_0)
unnamed: P6.2, U2.14 (IO_1_1)
unnamed: P6.3, U2.15 (IO_1_2)
unnamed: P6.4, U2.16 (IO_1_3)
unnamed: P6.5, U2.17 (IO_1_4)
unnamed: P6.6, U2.19 (IO_1_5)
unnamed: P6.7, U2.20 (IO_1_6)
unnamed: P6.8, U2.21 (IO_1_7)
unnamed: P7.1, U2.22 (IO_2_0)
unnamed: P7.2, U2.24 (IO_2_1)
unnamed: P7.3, U2.25 (IO_2_2)
unnamed: P7.4, U2.26 (IO_2_3)
unnamed: P7.5, U2.31 (IO_2_4)
unnamed: P7.6, U2.32 (IO_2_5)
unnamed: P7.7, U2.33 (IO_2_6)
unnamed: P7.8, U2.35 (IO_2_7)
unnamed: P8.1, U2.36 (IO_3_0)
unnamed: P8.2, U2.37 (IO_3_1)
unnamed: P8.3, U2.38 (IO_3_2)
unnamed: P8.4, U2.40 (IO_3_3)
unnamed: P8.5, U2.41 (IO_3_4)
unnamed: P8.6, U2.42 (IO_3_5)
unnamed: P8.7, U2.43 (IO_3_6)
unnamed: P8.8, U2.44 (IO_3_7)
unnamed: P9.1, U2.45 (IO_4_0)
unnamed: P9.2, U2.47 (IO_4_1)
unnamed: P9.3, U2.48 (IO_4_2)
unnamed: P9.4, U2.49 (IO_4_3)
unnamed: P9.5, U2.50 (IO_4_4)
unnamed: P9.6, U2.52 (IO_4_5)
unnamed: P9.7, U2.53 (IO_4_6)
unnamed: P9.8, U2.54 (IO_4_7)



Board: 4 copper layers, 76.2 x 71.1 mm, 13 parts (8 on the bottom side), 51 nets.
